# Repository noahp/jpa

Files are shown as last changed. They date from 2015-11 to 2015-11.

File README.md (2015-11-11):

# JPA- *J*ST *P*rogramming *A*dapter
Little adapter board to connect standard PIC 6-pin or SWD 10-pin programming cables to Micro JST 1.0mm cables.
# 3D Render
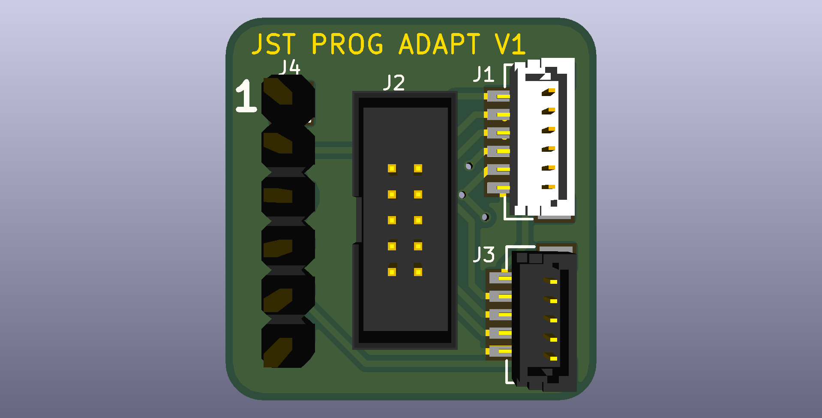
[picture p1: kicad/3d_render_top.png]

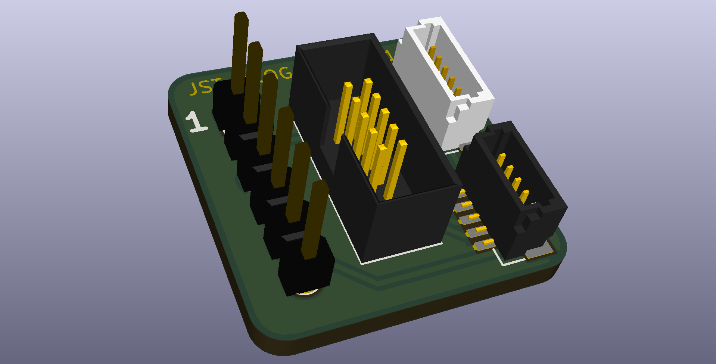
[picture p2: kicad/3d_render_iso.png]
iso

# PCB Render
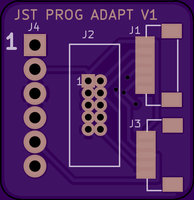
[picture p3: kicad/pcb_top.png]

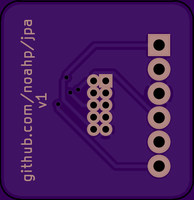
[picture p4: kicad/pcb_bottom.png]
bottom

# Part reference
[6-pin jst header](http://www.aliexpress.com/item/SM06B-SRSS-TB-LF-SN-CONN-RCPT-SR-6-POS-1-0MM-TIN-JST-Connectors-SM06BSRSSTBLFSN/1156361078.html)  
[6-pin jst cable](http://www.aliexpress.com/item/Wholesale-100pcs-Micro-JST-SH-1-0mm-Pitch-6-Pin-Female-Connector-with-Wire-jst-6pin/32299265934.html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,searchweb201644_5,searchweb201560_9)  
[5-pin jst header](http://www.digikey.com/product-detail/en/SM05B-SRSS-TB(LF)(SN)/455-1805-1-ND/926876)  
[5-pin jst cable](http://www.aliexpress.com/item/10pcs-Micro-JST-1-0mm-5pin-Connector-plug-with-wire/32506663955.html)  
[10-pin header](http://www.digikey.com/product-detail/en/3220-10-0100-00/1175-1627-ND/3883661)  
[10-pin smt header](http://www.digikey.com/product-detail/en/3220-10-0300-00/1175-1629-ND/3883266)  
[6-pin 0.1" header](http://www.digikey.com/product-detail/en/SM06B-SRSS-TB(LF)(SN)/455-1806-1-ND/926877)

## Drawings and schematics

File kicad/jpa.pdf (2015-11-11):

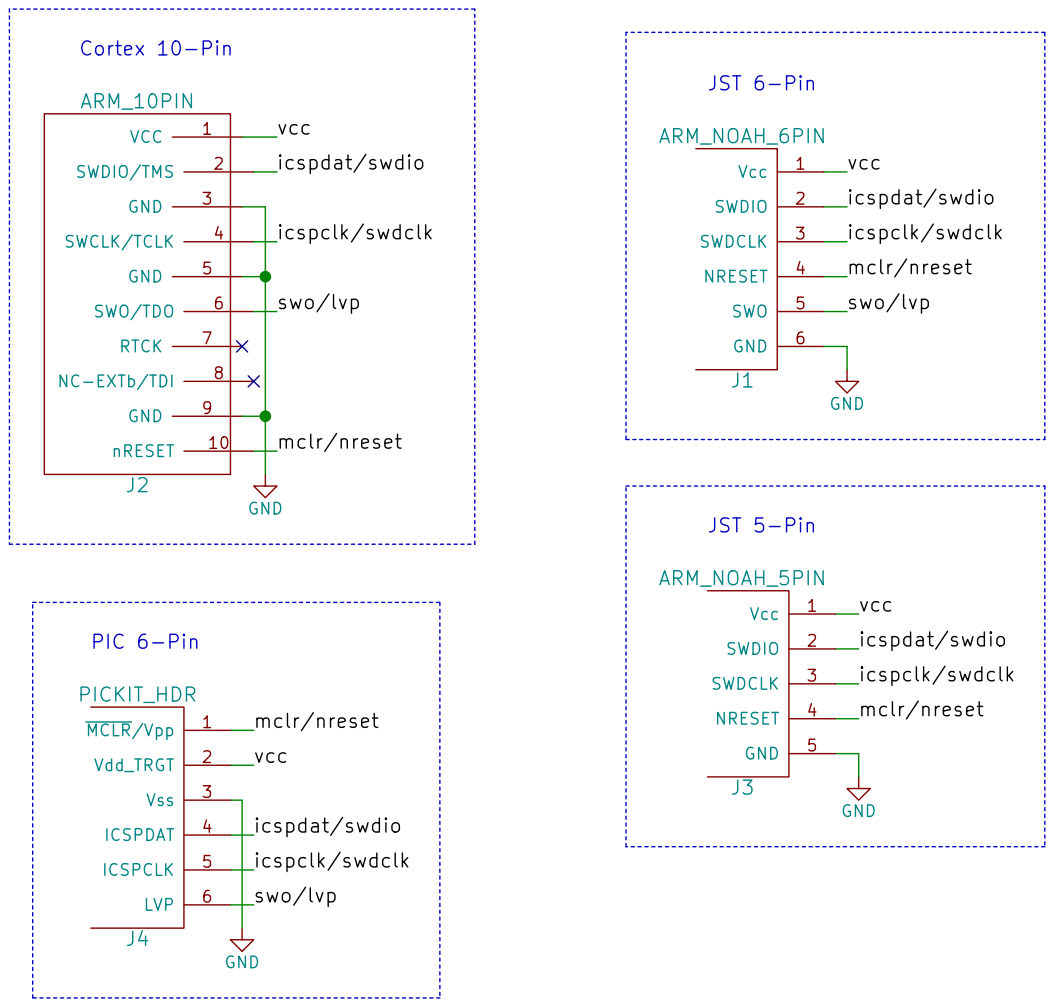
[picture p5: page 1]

JST 6-Pin
mclr/nreset vcc GND
icspdat/swdio
icspclk/swdclk

File: jpa.sch Sheet: /

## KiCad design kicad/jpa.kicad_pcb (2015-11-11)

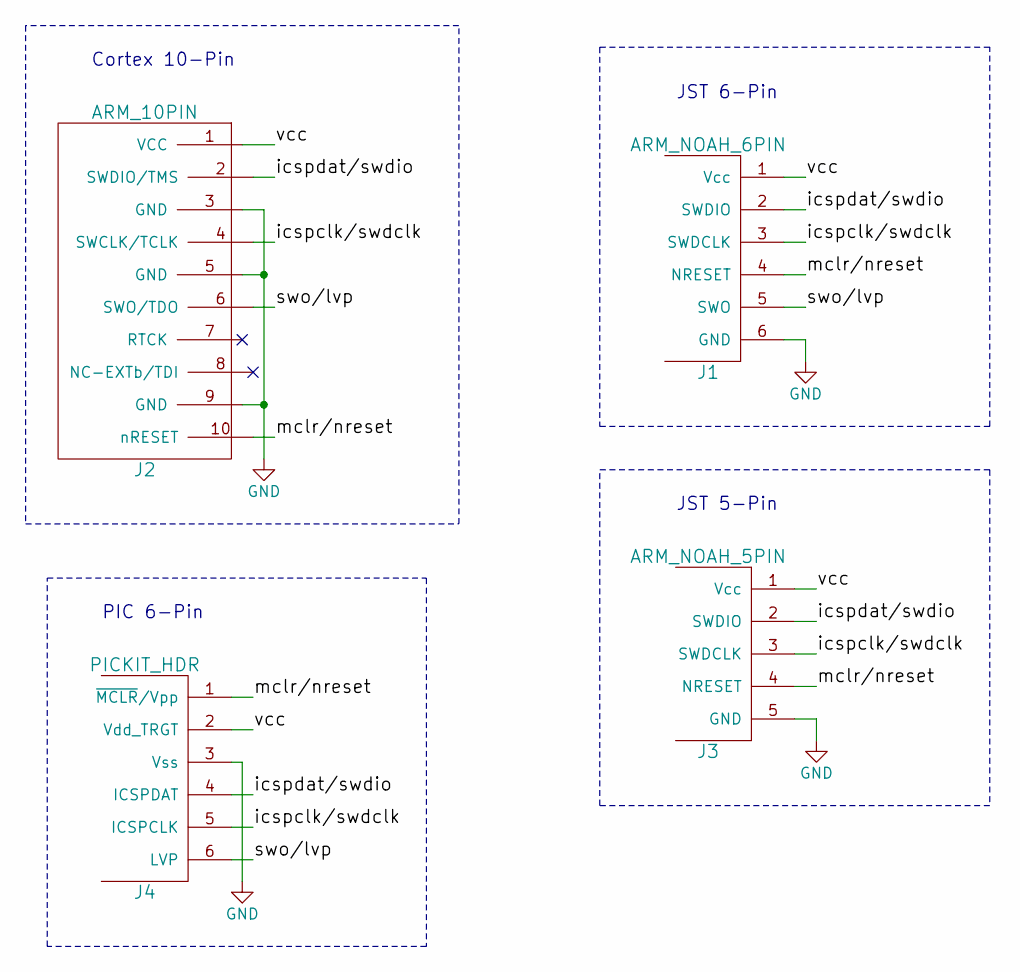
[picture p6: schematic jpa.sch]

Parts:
J1: ARM_NOAH_6PIN; SMD_JST_6_PIN_VERT
J2: ARM_10PIN; ARM_10_PIN
J3: ARM_NOAH_5PIN; SMD_JST_5_PIN_VERT
J4: PICKIT_HDR; TH_6X1_HDR

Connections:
/icspclk/swdclk: J1.3 (SWDCLK), J2.4 (SWCLK/TCLK), J3.3 (SWDCLK), J4.5 (ICSPCLK)
/icspdat/swdio: J1.2 (SWDIO), J2.2 (SWDIO/TMS), J3.2 (SWDIO), J4.4 (ICSPDAT)
/mclr/nreset: J1.4 (NRESET), J2.10 (nRESET), J3.4 (NRESET), J4.1 (~MCLR~/Vpp)
/swo/lvp: J1.5 (SWO), J2.6 (SWO/TDO), J4.6 (LVP)
/vcc: J1.1 (Vcc), J2.1 (VCC), J3.1 (Vcc), J4.2 (Vdd_TRGT)
GND: J1.6 (GND), J2.3 (GND), J2.5 (GND), J2.9 (GND), J3.5 (GND), J4.3 (Vss)

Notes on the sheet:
Cortex 10-Pin
PIC 6-Pin
JST 6-Pin
JST 5-Pin

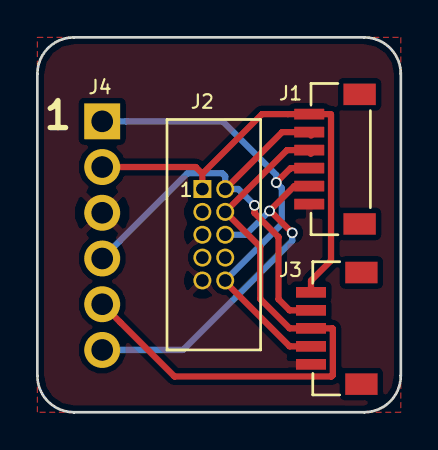
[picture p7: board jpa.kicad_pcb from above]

Board: 2 copper layers, 20.2 x 20.8 mm, 4 parts (0 on the bottom side), 6 nets.

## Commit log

2015-11-03 add blank files
    [picUsbProg.kicad_pcb, picUsbProg.sch]
2015-11-03 add normal kicadlib
2015-11-03 usb Micro AB connector connected to 3 debug headers- arm 10pin, pic 6 pin, noah-arm 5pin (micro jst).
    [picUsbProg.sch]
2015-11-04 schematic done
    [jpa.sch]
2015-11-10 update arm 6-pin header
    [jpa.sch]
2015-11-10 place components, still need a footprint for pic connector
    [jpa.kicad_pcb, jpa.sch]
2015-11-11 layout, gerbers, models done
    [jpa-B_Cu.gbr, jpa-B_Mask.gbr, jpa-B_SilkS.gbr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]
2015-11-11 add pcb renders
2015-11-11 fix some unconnected nets on the layout
    [jpa-B_Cu.gbr, jpa-B_Mask.gbr, jpa-B_SilkS.gbr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]
2015-11-11 new renders, tighter layout (only saves ~0.60$ osh cost)
    [jpa-B_Cu.gbr, jpa-B_Mask.gbr, jpa-B_SilkS.gbr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]
